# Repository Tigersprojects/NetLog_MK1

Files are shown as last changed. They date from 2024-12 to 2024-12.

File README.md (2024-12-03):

# NetLog MK1
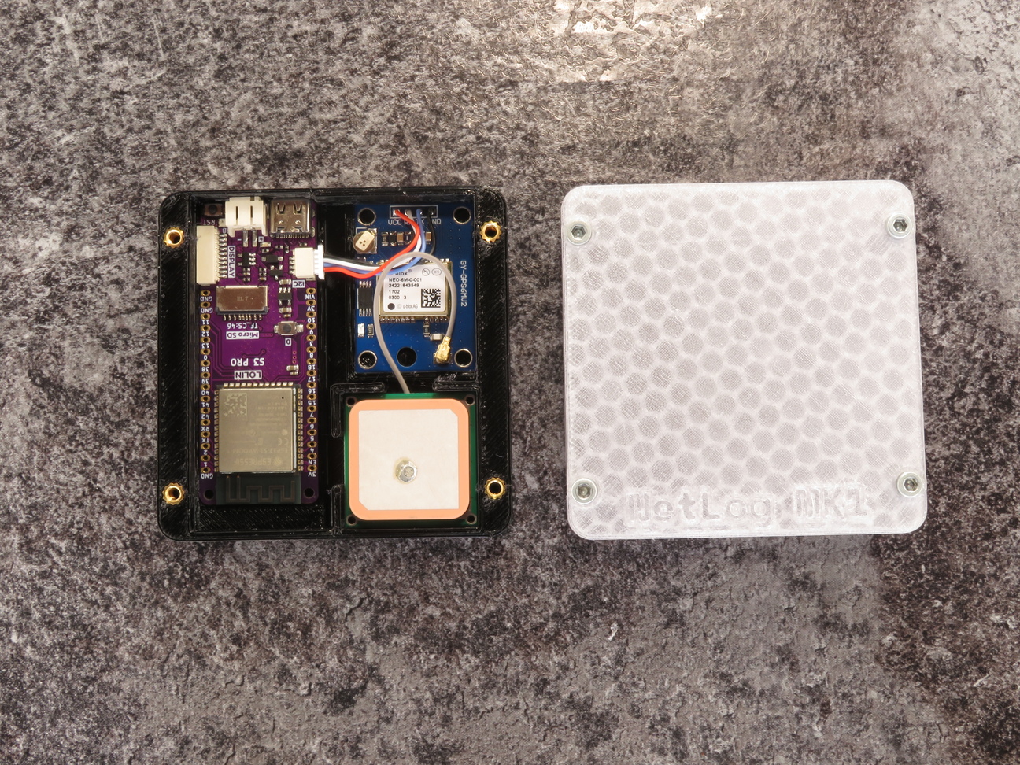
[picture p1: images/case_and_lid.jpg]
NetLog MK1 top view

The NetLog MK1 is a WiFi network scanning (wardriving) device based on
the ESP32-S3 and an inexpensive GPS module.

The NetLog MK1 is designed to be operated from a power bank or car USB charger.
The networks are stored in a CSV file on a FAT12 or FAT16 filesystem.

The NetLog MK1 will appear as a USB disk once connected to a computer.
From there, you can open the CSV file with any spreadsheet software (like LibreOffice, Google Docs, etc).

- [Build your own](docs/build_tutorial.md)
- [Flashing the firmware](docs/flashing_tutorial.md)

## RGB LED light codes
| Light code | Meaning |
|---|---|
| Static yellow  | Device starting |
| Static red | FS error. Format with FAT12 or FAT16  |
| Blinking green | Establishing GPS fix |
| Blinking red | Could not communicate with GPS module |
| White blink | Network found |

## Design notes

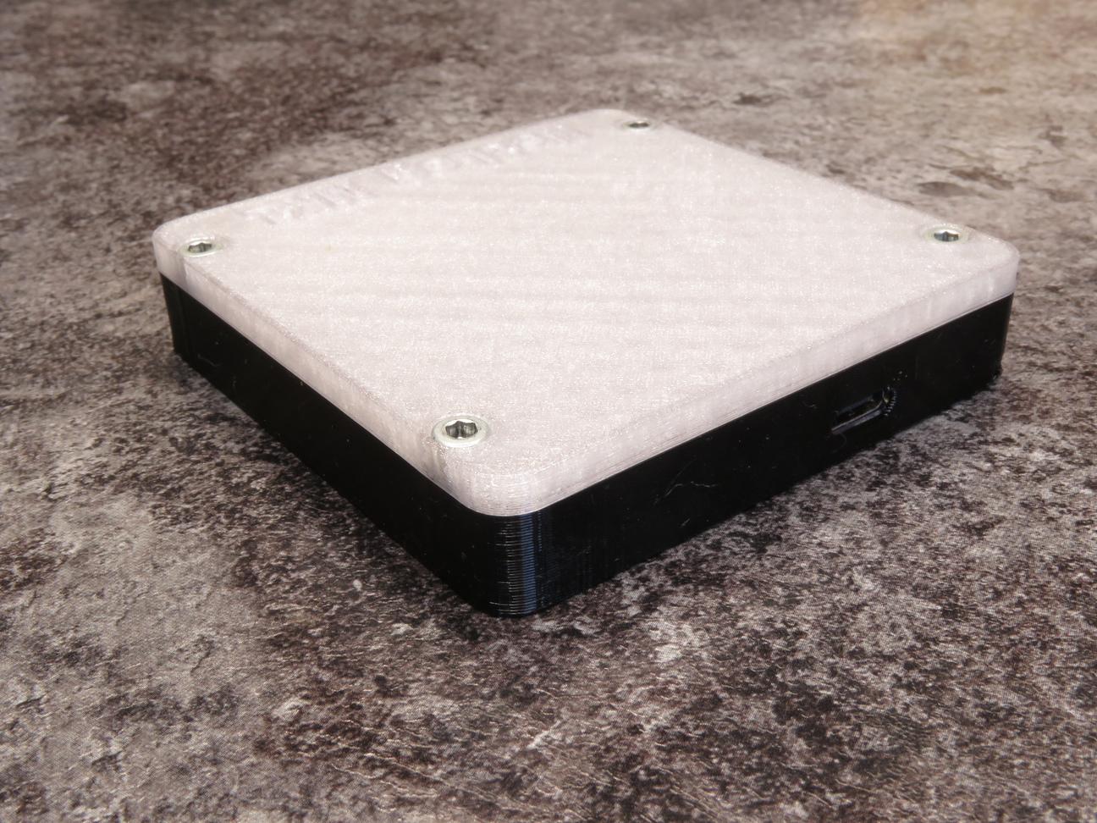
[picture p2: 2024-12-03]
images/side.jpg

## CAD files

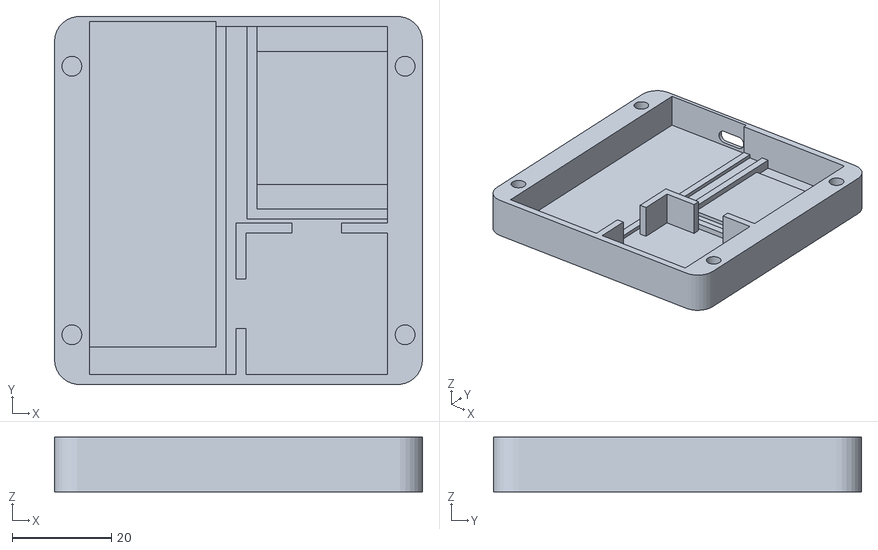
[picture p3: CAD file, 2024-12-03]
case.stl
74.0 x 74.0 x 11.0

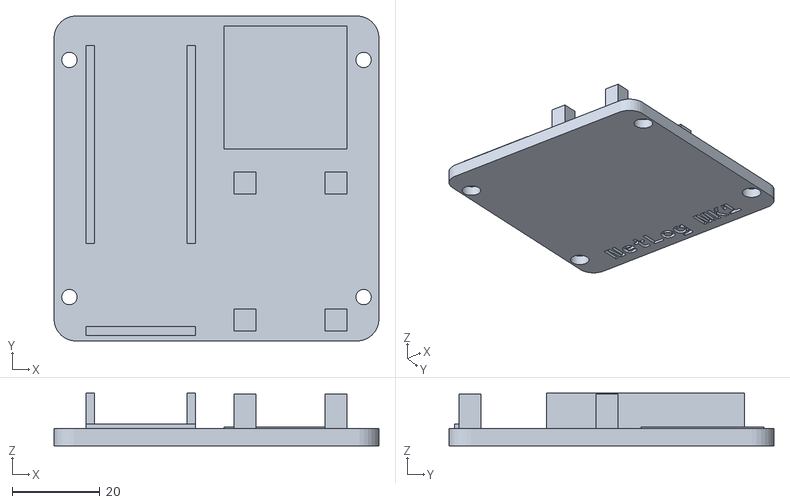
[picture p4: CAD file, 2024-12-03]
lid.stl
74.0 x 74.0 x 12.0

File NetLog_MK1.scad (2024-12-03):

/*
  Case for the NetLog MK1.

  Use with M3 threaded inserts
  and M3 hex socket cap screws.
  
  This file is a mess.
*/


$fn=30;

// Area for the components, e.g. GPS module, MCU, antenna //
case_x = 60;
case_y = 70;
case_z = 9;

// Mainboard size //
mainb_l = 65.5;
mainb_w = 25.5;
mainb_h = 1;

// GPS module size //
gps_l = 36.75;
gps_w = 26.25;
gps_h = 1.5;

// GPS antenna size //
gpsa_l = 28.5;
gpsa_w = 28.5;
gpsa_h = 9;

// Mainboard USB-C connector offsets //
mainb_usb_x = 16;
mainb_usb_z = 0.75;

// Tolerance offset //
tolerance_offset = 0.25;

// Other stuff //
wall_thickness = 2;

box = true;
lid = true;

lid_thickness = 4;

text_font = "Space Mono:style=Bold";


// A hole for a screw //
module screwHole() {
  translate([2.75, 2.875, 3]) cylinder(1, d=3.5);
  translate([2.75, 2.875]) cylinder(3, d=5.75);
}


// Box //
if (box) {

  // Rounded corners //
  for (i = [0 : 1 : 1]) {
    difference() {

      translate([
        5 + i * (case_x + wall_thickness * 2), 5
      ]) hull() {
        
        cylinder(case_z + wall_thickness, d=5 * 2);
        
        translate([0, case_y - 10 + wall_thickness * 2])
          cylinder(case_z + wall_thickness, d=5 * 2);
      }

      translate([
        5 + i * (case_x + wall_thickness * 2 - 5), 0
      ]) cube([
        5, case_y + wall_thickness * 2,
        case_z + wall_thickness
      ]);
      

      // Holes for screws //
      for (j = [0 : 1 : 1]) translate([
        i * (case_x + 5 + wall_thickness * 2 - 2) + 3.5,

        10 + j *
        (case_y - 20 + wall_thickness * 2),
        
        case_z + wall_thickness - 10.5
      ]) cylinder(10.5, d=4);
    }
  }

  translate([5, 0]) {

    // Box for the components //
    difference() {
      cube([
        case_x + wall_thickness * 2,
        case_y + wall_thickness * 2,
        case_z + wall_thickness
      ]);
      
      translate([wall_thickness, wall_thickness, wall_thickness]) cube([
        case_x,
        case_y,
        case_z
      ]);
      

      // Holes for screws //
      for (i = [0 : 1 : 1]) for (j = [0 : 1 : 1]) translate([
        i * (case_x + 5 + wall_thickness * 2 - 2) - 1.5,
        
        10 + j *
        (case_y - 20 + wall_thickness * 2),
        
        case_z + wall_thickness - 10.5
      ]) cylinder(10.5, d=4);


      // Small pits under GPS module //
      translate([
        case_x - gps_w + wall_thickness,
        case_y - gps_l + wall_thickness,
        wall_thickness / 2
      ]) cube([gps_w, 5, wall_thickness / 2]);

      translate([
        case_x - gps_w + wall_thickness,
        case_y - 5 + wall_thickness,
        wall_thickness / 2
      ]) cube([gps_w, 5, wall_thickness / 2]);


      // Hole for USB-C port //
      translate([
        wall_thickness + 1.875 + mainb_usb_x,
        wall_thickness * 2 + case_y,
        wall_thickness + 1.875 + mainb_usb_z
      ]) { 

        rotate([90, 90]) {
          hull() {
            cylinder(wall_thickness, d=3.5);
            translate([0, 5]) cylinder(wall_thickness, d=3.5);
          }
        }
      }

      // Make the wall thinner where the mainboard goes
      translate([wall_thickness, wall_thickness + case_y, wall_thickness])
        cube([mainb_w, wall_thickness / 2, case_z]);
    }

    // Holders for the mainboard //
    translate([wall_thickness + mainb_w, wall_thickness, wall_thickness])
      cube([wall_thickness, case_y, mainb_h]);
  
    translate([wall_thickness, wall_thickness, wall_thickness])
      cube([mainb_w, case_y - mainb_l + wall_thickness / 2, mainb_h]); 

    // Holders for the GPS module //
    translate([case_x - gps_w, case_y - gps_l, wall_thickness])
      cube([wall_thickness, gps_l + wall_thickness, gps_h]);
  
    translate([
      case_x - gps_w + wall_thickness,
      case_y - gps_l,
      wall_thickness
    ]) cube([gps_w, wall_thickness, gps_h]);
  

    // Holders for the GPS antenna //
    difference() {
      translate([case_x - gpsa_w, wall_thickness, wall_thickness])
        cube([gpsa_w + wall_thickness, gpsa_l + wall_thickness, gpsa_h]);

      translate([
        case_x - gpsa_w + wall_thickness,
        wall_thickness,
        wall_thickness
      ]) cube([gpsa_w, gpsa_l, gpsa_h]);

      translate([
        case_x - gpsa_w / 2 + wall_thickness - 5,
        gpsa_l + wall_thickness,
        wall_thickness
      ]) cube([10, wall_thickness, gpsa_h]);

      translate([
        case_x - gpsa_w,
        gpsa_l / 2 + wall_thickness - 5,
        wall_thickness
      ]) cube([wall_thickness, 10, gpsa_h]);
    }
  }
}


// Lid //
if (lid) {  
  translate([0, case_y + wall_thickness * 2 + 10]) {

    // Rounded corners //
    for (i = [0 : 1 : 1]) {
      difference() {

        translate([
          5 + i * (case_x + wall_thickness * 2), 5
        ]) hull() {
          
          cylinder(lid_thickness, d=5 * 2);
          
          translate([0, case_y - 10 + wall_thickness * 2])
            cylinder(lid_thickness, d=5 * 2);
        }

        translate([
          5 + i * (case_x + wall_thickness * 2 - 5), 0
        ]) cube([
          5, case_y + wall_thickness * 2,
          lid_thickness
        ]);
        

        // Screw holes //
        for (j = [0 : 1 : 1]) translate([
          i * (case_x + 5 + wall_thickness * 2 - 2) + 0.75,

          7.125 + j *
          (case_y - 20 + wall_thickness * 2), 0
        ]) screwHole();
      }
    }


    // Box for the lid //
    difference() {
      translate([5, 0]) cube([
        case_x + wall_thickness * 2,
        case_y + wall_thickness * 2,
        lid_thickness
      ]);


      // Text //
      translate([
        case_x / 2 + 5 + wall_thickness,
        case_y + wall_thickness * 2 - 2,
        wall_thickness / 2
      ]) rotate([180]) linear_extrude(wall_thickness / 2) 
        text(
          "NetLog MK1",
          6, font=text_font,
          halign="center",
          valign="bottom"
        );


      // More screw holes //
      for (i = [0 : 1 : 1]) for (j = [0 : 1 : 1]) translate([
        i * (case_x + 5 + wall_thickness * 2 - 2) + 0.75,

        7.125 + j *
        (case_y - 20 + wall_thickness * 2), 0
      ]) screwHole();
    }


    // Support for the thin mainboard wall //
    translate([5 + wall_thickness + tolerance_offset,
              tolerance_offset + wall_thickness / 2, lid_thickness])

              cube([mainb_w - tolerance_offset * 2, wall_thickness, 1]);


    translate([
      5 + wall_thickness,
      wall_thickness,
      lid_thickness
    ]) {
      
      // Holders for mainboard //
      for (i = [0 : 1 : 1]) translate([
        tolerance_offset + i * (mainb_w - wall_thickness - tolerance_offset * 2),
        case_y - 45 - tolerance_offset - (case_y - mainb_l)
      ]) cube([wall_thickness, 45, case_z - mainb_h]);


      // Holder for GPS antenna (+0.25mm height) //
      translate([
        case_x + tolerance_offset - gpsa_w,
        case_y + tolerance_offset - gpsa_l
      ]) cube([
        gpsa_w - tolerance_offset * 2,
        gpsa_l - tolerance_offset * 2,
        case_z - gpsa_h + 0.25
      ]);

      
      // Holders for GPS module (+0.25mm height) //
      for (i = [0 : 1 : 1]) for (j = [0 : 1 : 1]) translate([
        case_x - 5 - tolerance_offset - i * (gps_w - 5 - tolerance_offset * 2),
        tolerance_offset + j * (gps_l - 5 - tolerance_offset * 2),
      ]) cube([5, 5, case_z - gps_h + 0.25]);
    }
  }
}

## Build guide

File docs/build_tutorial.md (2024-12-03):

# Building a NetLog MK1
To build a NetLog MK1, you need the following tools and parts:

| Tools                 |
|-----------------------|
| Soldering iron        |
| Flushcutters          |
| 3D printer            |
| Wire strippers        |
| 2.5mm hex screwdriver |

| Parts                         |
|-------------------------------|
| LOLIN S3 Pro dev board        |
| 4x M3 threaded inserts        |
| 4x M3 hex socket cap screws   |
| GY-NEO6MV2 GPS module         |
| 28 x 28 x ~9mm uFL GPS antenna |
| JST SH 4-pin connector        |
| 4x JST SH cables              |

## Step 1: Building the case
Print `case.stl` with PLA or PET(G). Next, insert four M3 threaded inserts into the screw holes.
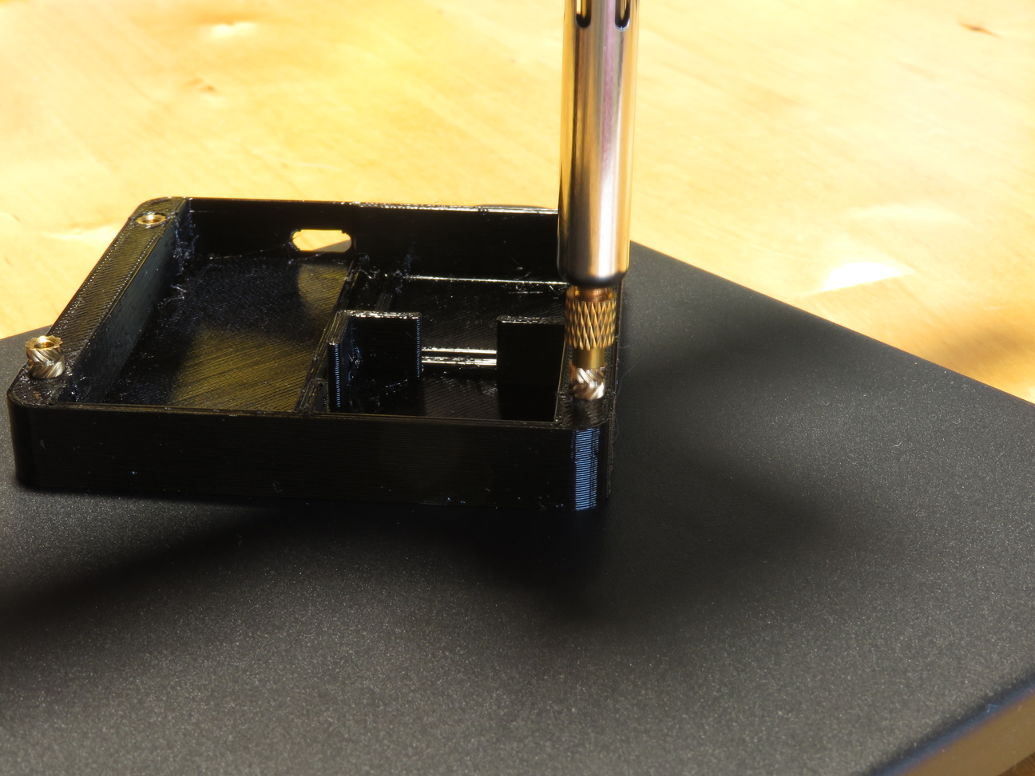
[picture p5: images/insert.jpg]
Inserting the inserts


When you're done, the case should look something like this:
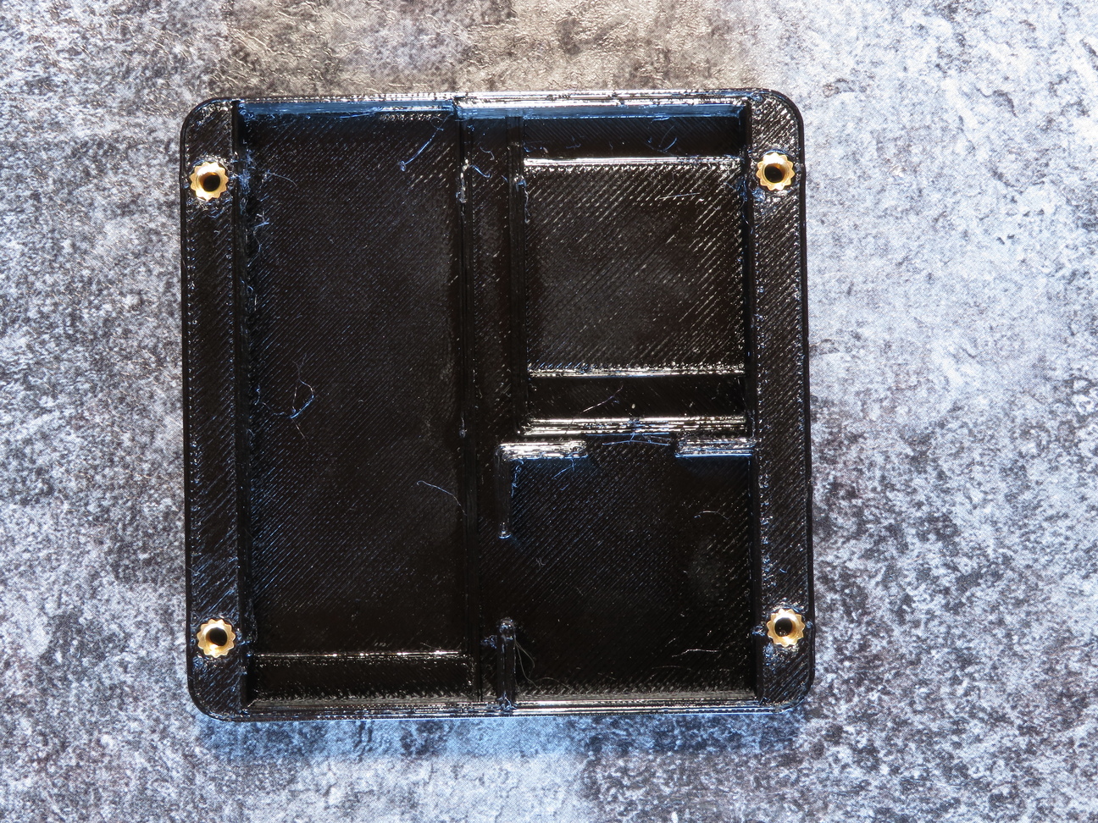
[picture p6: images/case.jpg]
Finished case


## Step 2: Preparing the GPS module
Next, we'll connect a JST SH (1.0mm) 4-pin cable to the GPS module.

I recommend getting a set that has pre-crimped cables, as manually crimping these connectors can be difficult.
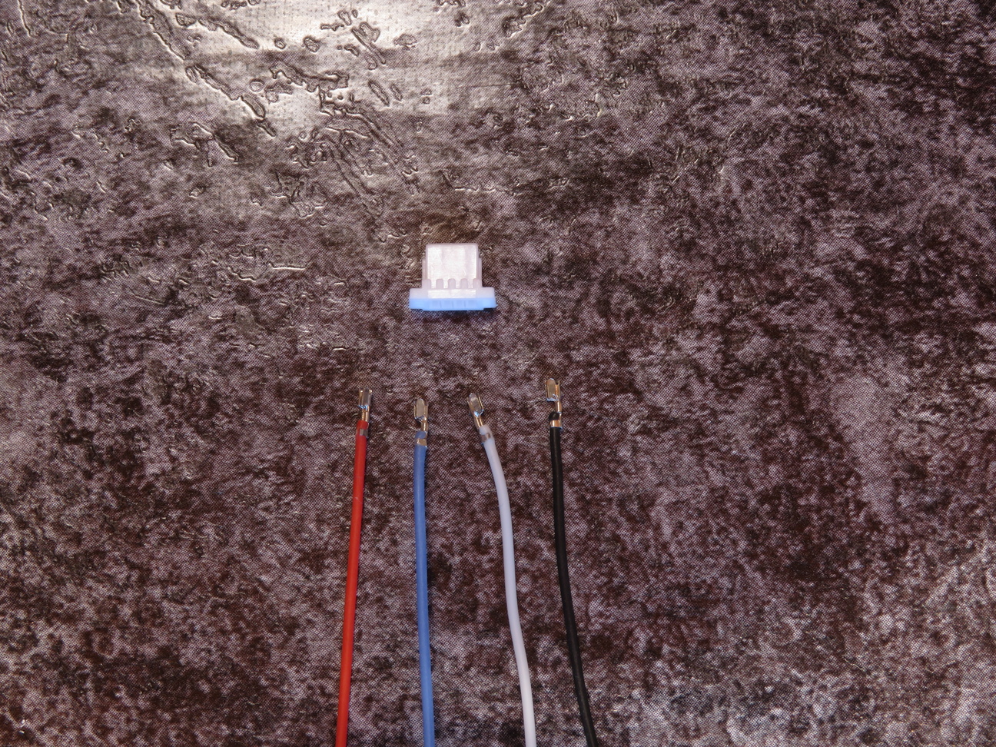
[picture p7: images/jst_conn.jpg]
JST connector with cables


Insert the cables into the connector, and cut the ends so they are about
5cm long, and strip the ends of the cables. Then, solder them to the GPS module with the pinout shown in the image below:
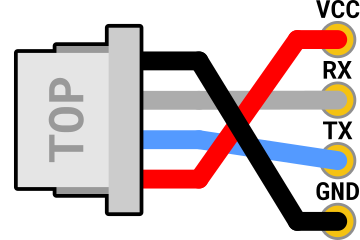
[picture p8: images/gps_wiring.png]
Connector pinout


This is what the result should look like:
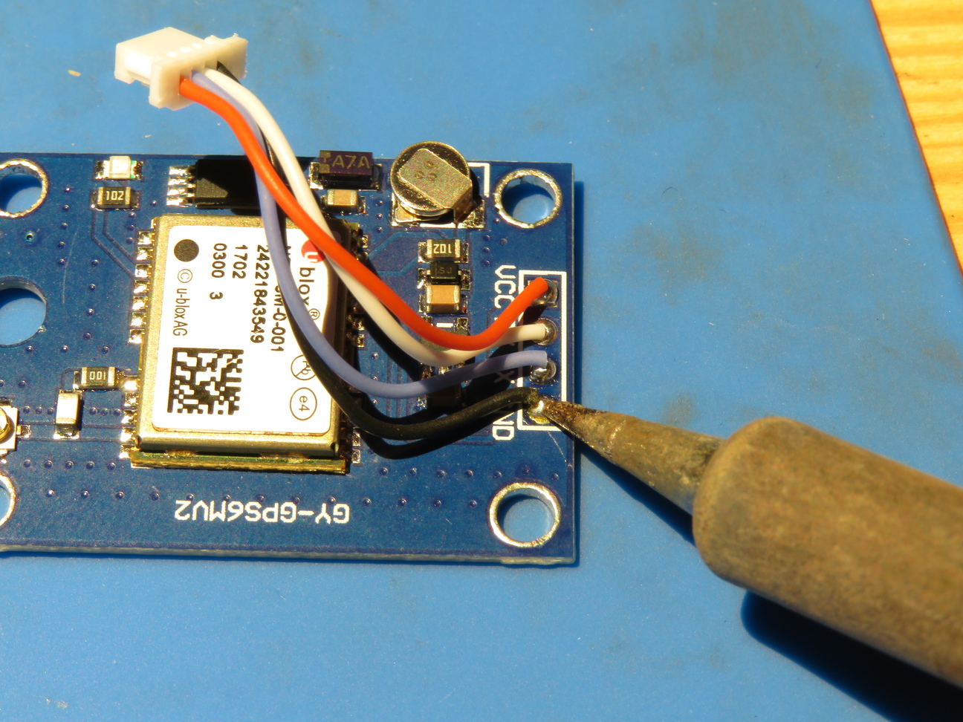
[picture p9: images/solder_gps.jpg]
Result


For the GPS module to fit in the case, you will need to cut the solder blobs on the bottom of the GPS module:
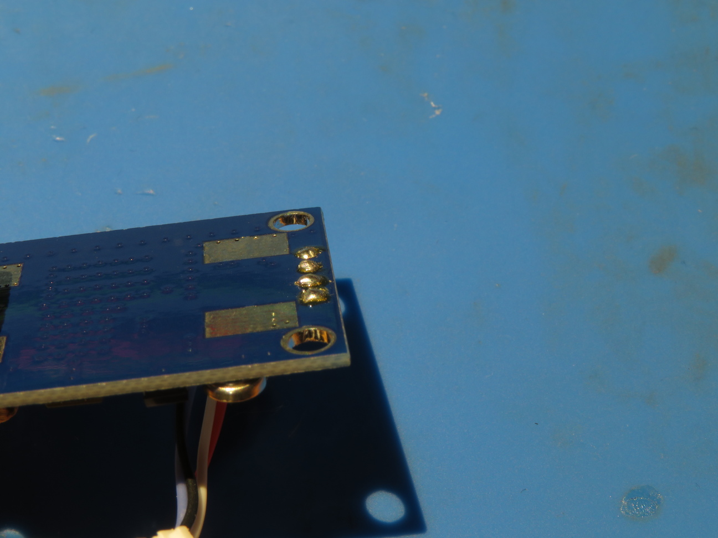
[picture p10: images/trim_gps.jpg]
Flush solder blobs


## Step 3: Printing the cover
Print `lid.stl` with **clear** PLA or PET(G). This is so that the LEDs can shine through the cover.
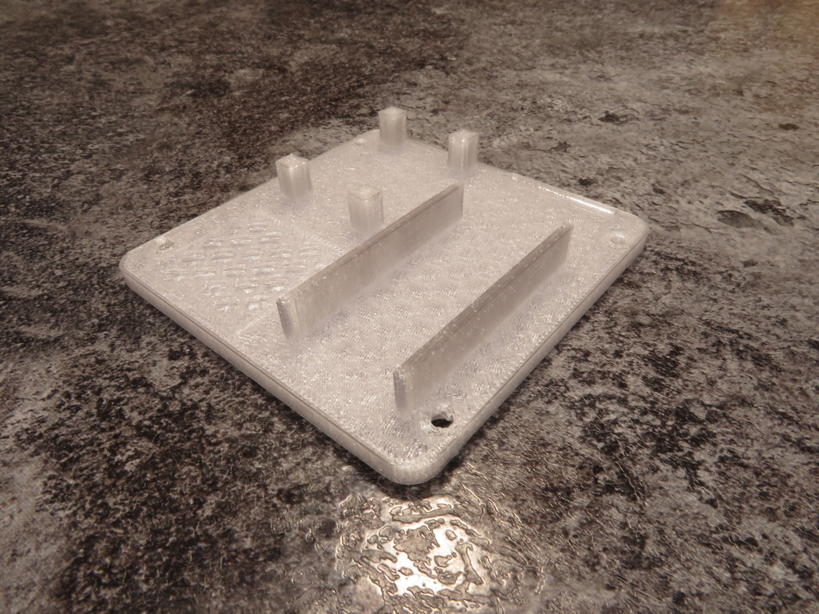
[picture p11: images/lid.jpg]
Cover

Those weird towers on the cover hold the components in place.

## Step 4: Assembling the device
Now we have the case, cover, and components ready for assembly.
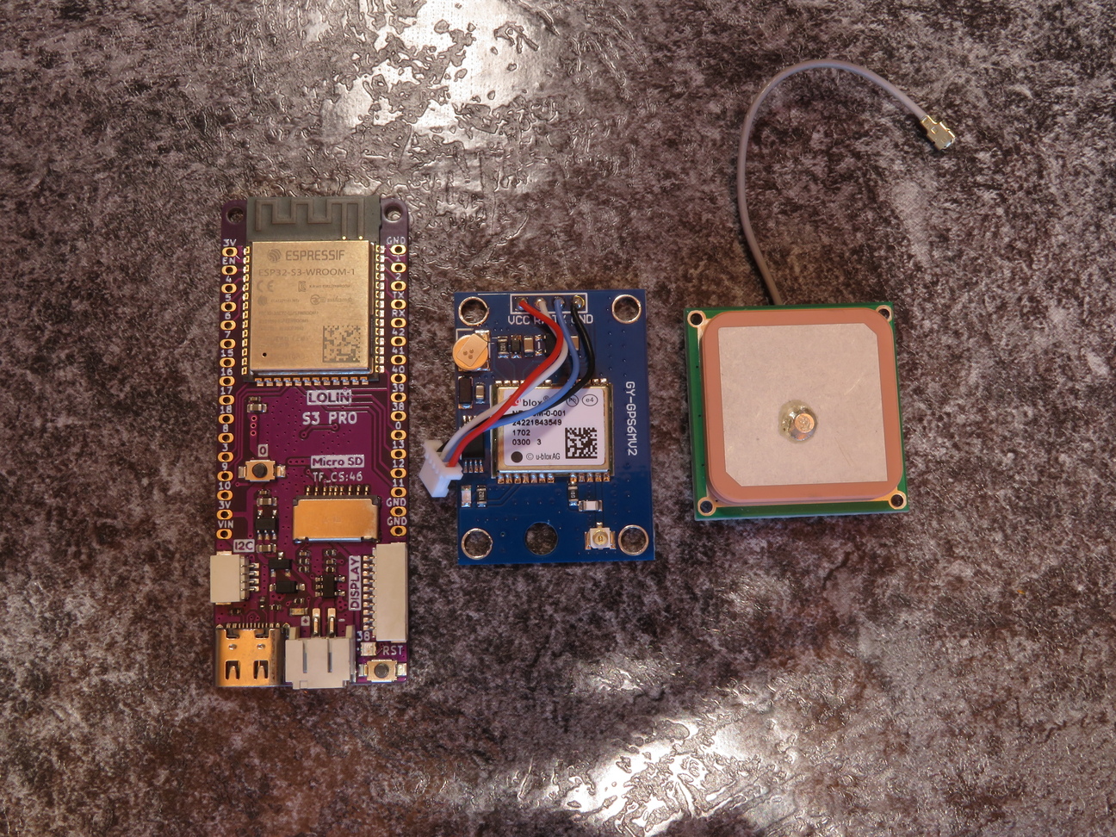
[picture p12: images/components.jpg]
Components


Put the components in the case like this:
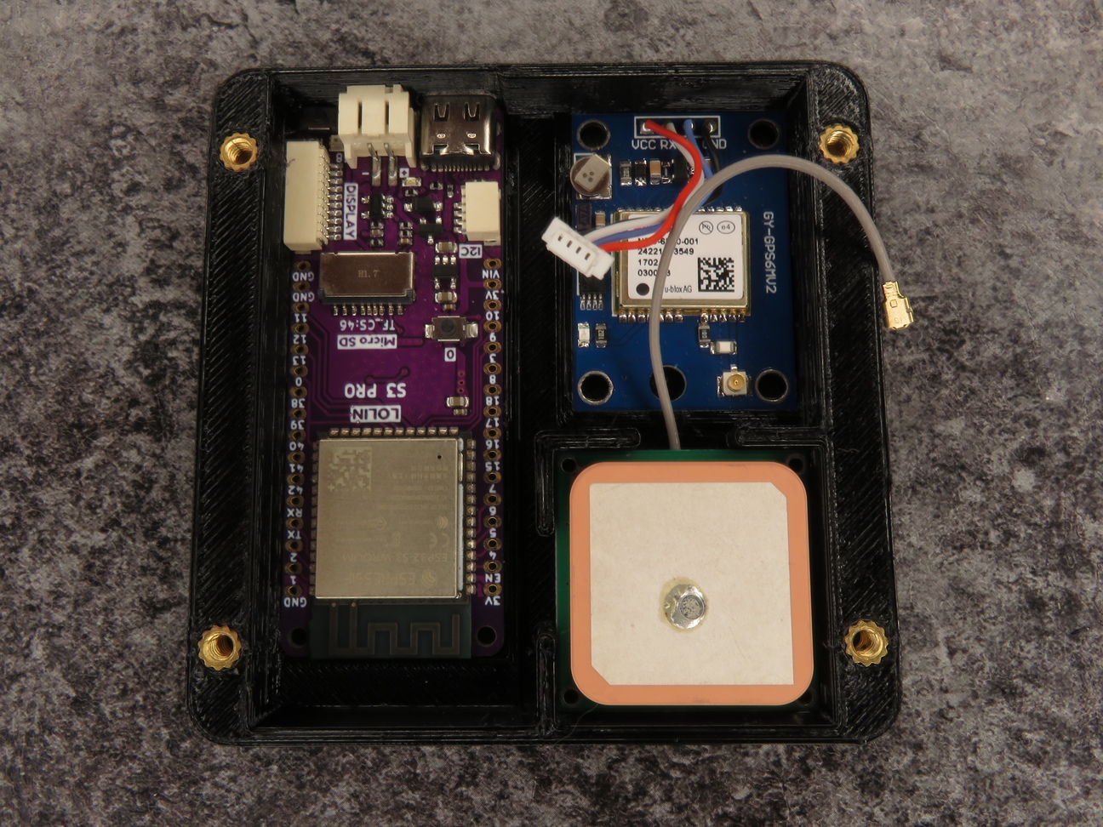
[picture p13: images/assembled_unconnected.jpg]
Components in case


> Note: Due to tight tolerances, getting the components in their slots may take some force.

Next, connect the JST cable of the GPS module into the S3 Pro's I2C port, and the GPS antenna's uFL connector to the GPS module.
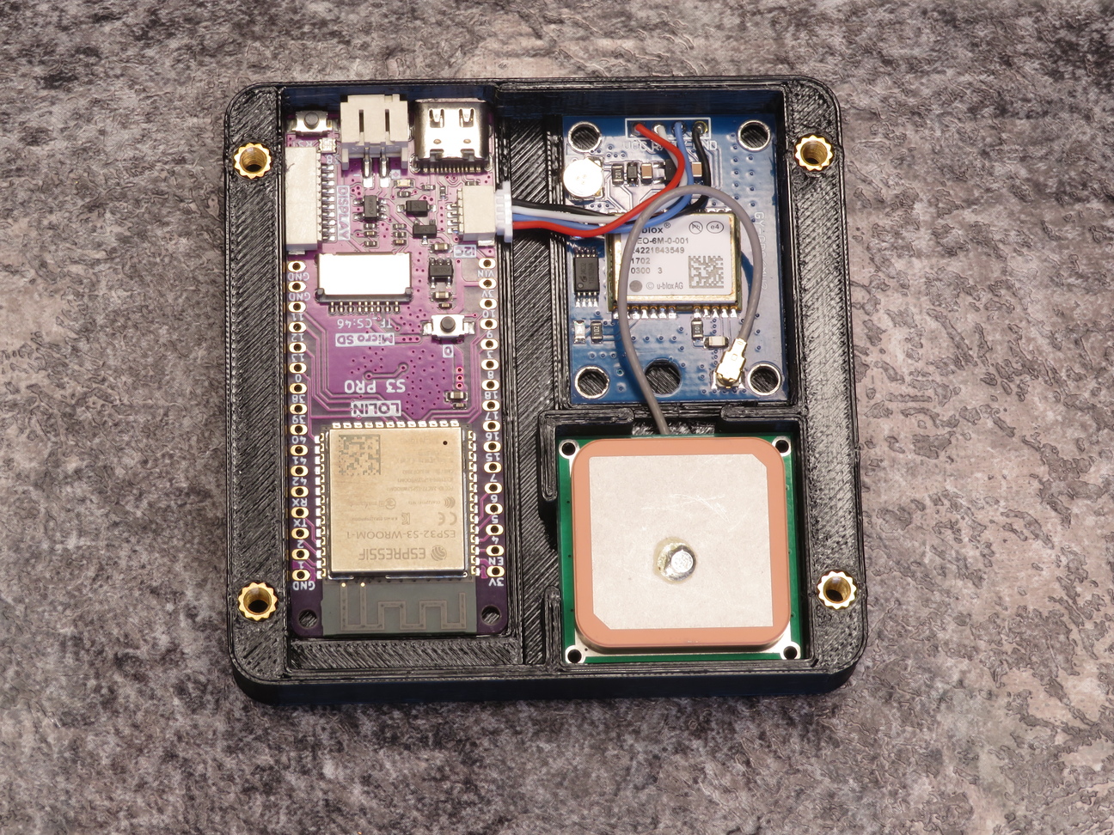
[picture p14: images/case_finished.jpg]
Case with cables connected


> While the 4-pin JST connector on the S3 Pro is intended for I2C,
    the versatility of the ESP32's GPIO pins allows us to use it for
    UART as well.

> Before attaching the cover, it may be a good idea to [flash the firmware.](flashing_tutorial.md)

Now, we can screw the cover on to the case:
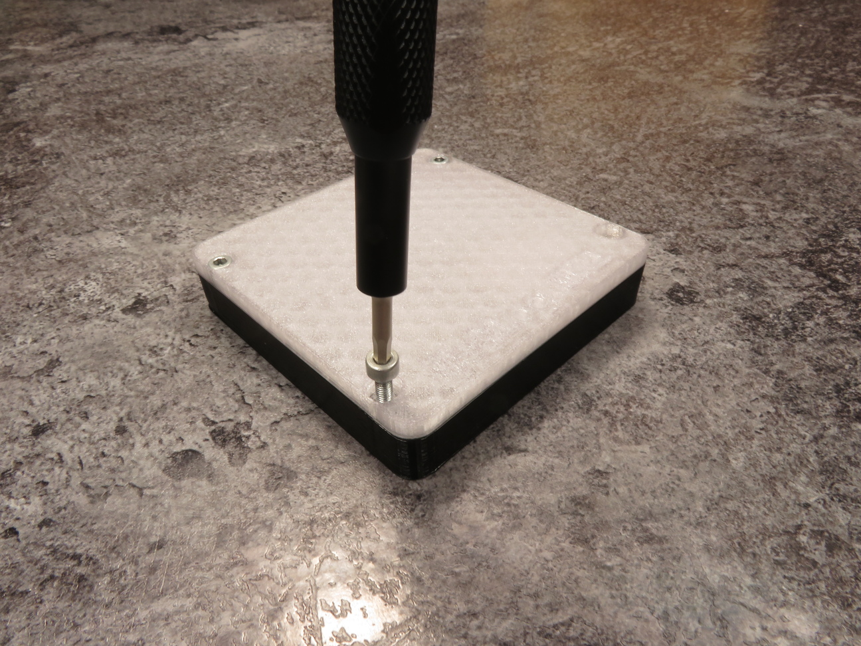
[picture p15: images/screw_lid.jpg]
Screwing cover on case


With this, your NetLog MK1 is finished!
In case you haven't already, you now just have to [flash the firmware.](flashing_tutorial.md)

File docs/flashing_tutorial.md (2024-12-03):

# Flashing the Firmware

Open `NetLog_MK1.ino` in Arduino IDE and install the following
boards and libraries:

1. [Install the ESP32 boards](https://docs.espressif.com/projects/arduino-esp32/en/latest/installing.html)

2. Install the following libraries:
    - TinyGPSplus
    - Adafruit NeoPixel
    - SdFat
    - Adafruit SPIFlash
    - Adafruit TinyUSB

If you want, you can configure some parameters in `config.h`. Next,
select `LOLIN S3 Pro` and the connected serial port in the board selector.

Then, under the _Tools_ menu:

- enable _USB CDC On Boot_
- set _USB Mode_ to _USB-OTG (TinyUSB)_
- set _Partition Scheme_ to _16M Flash (2MB APP/12.5MB FATFS)_

Once you've done that, upload the sketch by clicking on the upload button.
Selecting the board

> Flashing the firmware through hardware CDC is not possible
    once the device is mounted as a USB flash drive.
    Instead of booting into DFU mode, you can set _Upload Mode_ to
    _USB-OTG CDC (TinyUSB)_.

Once you've flashed the firmware and restarted the device, the LED will glow yellow and then turn solid red.
This indicates a filesystem error, as we first have to format the FATFS partition with FAT12 or FAT16.

On Linux you can format the device by running `sudo mkfs.vfat /dev/sdX`,
with `sdX` being the block device, which you can find by running `lsblk`.

Now the device should be ready for use.

> The BSSIDs text file the device creates contains the BSSID
    of every network it has already found (which networks it should ignore).

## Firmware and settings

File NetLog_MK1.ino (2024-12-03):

/*
  NetLog MK1 - The ESP32 WiFi logger
  by Tigersprojects

  Designed for an ESP32-S3 with a GPS module.

  Remember to set "USB CDC On Boot" to "Enabled"
  and "USB Mode" to "USB-OTG" under the Tools menu.

  You can usually set "Upload Mode" to
  "USB-OTG CDC (TinyUSB)" to avoid booting
  the device into DFU mode.

  Format the flash with FAT12 or FAT16
  for NetLog to work properly.
*/

#include <WiFi.h>

#include <Wire.h>
#include <TinyGPS++.h>
#include <Adafruit_NeoPixel.h>

#include "SPI.h"
#include "SdFat.h"
#include "Adafruit_SPIFlash.h"
#include "Adafruit_TinyUSB.h"

// For flashTransport definition
#include "flash_config.h"

#include "config.h"

// Define stuff //
String cur_ssid, csv_str;

char cur_bssid[18],
     temp_bssid[18],
     newline_bssid[19],
     temp_char;

bool exists = false,
     gps_new_data = false,
     flash_busy = false;

HardwareSerial neogps(1);
Adafruit_SPIFlash flash(&flashTransport);

FatVolume fatfs;
FatFile bssid_file;

TinyGPSPlus gps;
Adafruit_USBD_MSC usb_msc;


// Checks if a file exists
bool fileExists(const char *path) {
  FatFile file = fatfs.open(path);

  bool exists = file;
  if (exists) file.close();

  return exists;
}


// Writes to a file
void fileAppend(const char *path, const char *message) {
  File file = fatfs.open(path, FILE_WRITE);

  if (!file) return;

  file.print(message);
  file.close();
}


// Makes a string CSV-safe
String CSVSafeString(String input) {
  String output = "";

  // Double all quotes
  for (int c = 0; c < input.length(); c++) {
    output += ((input.charAt(c) == '"') ? "\"\"" : String(input.charAt(c)));
  }

  // Append and prepend quotes to the output
  output = "\"" + output + "\"";
  return output;
}


// Setup
void setup() {

  // Initialize NeoPixel
  rgb.begin();

  rgb.setPixelColor(0, rgb.Color(255, 255, 0));
  rgb.setBrightness(neopixel_brightness);

  rgb.show();

  // Init WiFi
  WiFi.mode(WIFI_STA);
  WiFi.disconnect();

  delay(1000);

  // Initialize storage
  flash.begin();

  // Configure usb_msc
  usb_msc.setID(netlog_vid, netlog_name, netlog_ver);
  usb_msc.setReadWriteCallback(msc_read_cb, msc_write_cb, msc_flush_cb);
  usb_msc.setCapacity(flash.size() / 512, 512);

  usb_msc.setUnitReady(true);
  usb_msc.begin();

  // Reattach if already mounted
  if (TinyUSBDevice.mounted()) {
    TinyUSBDevice.detach();
    delay(10);
    TinyUSBDevice.attach();
  }

  // Init fs on flash
  while (!fatfs.begin(&flash)) {
    rgb.setPixelColor(0, rgb.Color(255, 0, 0));
    rgb.show();

    delay(1000);
  }

  // Create necessary files if they don't exist
  if (!fileExists(data_filename)) {
    flash_busy = true;
    fileAppend(data_filename, "ssid,bssid,rssi,auth,coord,speed\n");
    flash_busy = false;
  }

  if (!fileExists(bssid_filename)) {
    flash_busy = true;
    fileAppend(bssid_filename, "");
    flash_busy = false;
  }

  // Connect to GPS
  neogps.begin(9600, SERIAL_8N1, GPS_RXD2, GPS_TXD2);
  delay(2000);

  // Startup successful (with cool fade effect)
  for (int b = 0; b < neopixel_brightness; b++) {
    rgb.setBrightness(neopixel_brightness - b);
    rgb.show();

    delay(5);
  }

  rgb.setPixelColor(0, rgb.Color(0, 0, 0));
  rgb.setBrightness(neopixel_brightness);
  rgb.show();

  delay(500);
}


// Loop
void loop() {

  // See if there is available data from the GPS module
  for (unsigned long start = millis(); millis() - start < 1000;) {
    while (neogps.available()) {
      if (gps.encode(neogps.read())) {
        gps_new_data = true;
      }
    }
  }

  // Start scanning networks if the GPS module has a connection
  if (gps.location.isValid() && gps.satellites.value() != 0) {

    // Make sure NeoPixel is off
    rgb.setPixelColor(0, rgb.Color(0, 0, 0));
    rgb.show();

    // Scan networks
    unsigned long networks_found = WiFi.scanNetworks();

    // Search for new networks
    for (int i = 0; i < networks_found; i++) {

      // Get SSID and stop at newline char ('\n')
      // (Yes, you can put newlines in SSIDs)    
      cur_ssid = WiFi.SSID(i).substring(0, WiFi.SSID(i).indexOf('\n'));

      // Get BSSID
      memset(cur_bssid, '\0', 18);
      WiFi.BSSIDstr(i).toCharArray(cur_bssid, 18);

      // Open BSSID file and make sure the BSSID doesn't already exist
      bssid_file = fatfs.open(bssid_filename);
      exists = false;

      while (bssid_file.available()) {

        // Check first character for maximum speed
        temp_char = bssid_file.read();

        if (temp_char == cur_bssid[0]) {

          // Read entire string if the characters match
          memset(temp_bssid, '\0', 18);

          while (temp_char != '\n') {
            strncat(temp_bssid, &temp_char, 1);
            temp_char = bssid_file.read();
          }

          if (strcmp(temp_bssid, cur_bssid) == 0) {
            exists = true;
            break;
          }

        } else {

          // Go to next newline if the characters don't match
          while (bssid_file.read() != '\n');
        }
      }

      bssid_file.close();


      // Save network info
      if (!exists) {

        // Flash NeoPixel to signal network
        rgb.setPixelColor(0, rgb.Color(255, 255, 255));
        rgb.show();

        delay(100);

        rgb.setPixelColor(0, rgb.Color(0, 0, 0));
        rgb.show();

        delay(100);

        // Add SSID, BSSID, and RSSI to CSV
        csv_str = CSVSafeString(cur_ssid) + "," +
                  CSVSafeString(cur_bssid) + "," +
                  CSVSafeString(String(WiFi.RSSI(i)) + " dBm") + ",";

        // Append auth to CSV
        switch (WiFi.encryptionType(i)) {
          case WIFI_AUTH_OPEN:
            csv_str += CSVSafeString("Open"); break;

          case WIFI_AUTH_WEP:
            csv_str += CSVSafeString("WEP"); break;

          case WIFI_AUTH_WPA_PSK:
            csv_str += CSVSafeString("WPA PSK"); break;

          case WIFI_AUTH_WPA2_PSK:
            csv_str += CSVSafeString("WPA2 PSK"); break;

          case WIFI_AUTH_WPA_WPA2_PSK:
            csv_str += CSVSafeString("WPA WPA2 PSK"); break;

          case WIFI_AUTH_WPA2_ENTERPRISE:
            csv_str += CSVSafeString("WPA2 Enterprise"); break;
          
          case WIFI_AUTH_WPA3_PSK:
            csv_str += CSVSafeString("WPA3 PSK"); break;

          case WIFI_AUTH_WPA2_WPA3_PSK:
            csv_str += CSVSafeString("WPA2 WPA3 PSK"); break;

          case WIFI_AUTH_WAPI_PSK:
            csv_str += CSVSafeString("WAPI PSK"); break;

          default:
            csv_str += CSVSafeString(String("Unknown Auth (" +
                      String(WiFi.encryptionType(i)) + ")"));
            break;
        
        } csv_str += ",";

        // Save NetLog position and speed (skipping latitude)
        csv_str += CSVSafeString(String(
          ((gps.location.lat() >= 0) ? "+" : "") + String(gps.location.lat(), 6) + " " +
          ((gps.location.lng() >= 0) ? "+" : "") + String(gps.location.lng(), 6)
        )) + ",";

        csv_str += CSVSafeString(String(gps.speed.kmph(), 1) + " km/h") + "\n";

        // Create BSSID with a newline
        memset(newline_bssid, '\0', 19);
        strncpy(newline_bssid, cur_bssid, 18);
        strncat(newline_bssid, "\n", 1);

        // Append data to files
        flash_busy = true;

        if (!fileExists(data_filename))
          fileAppend(data_filename, "ssid,bssid,rssi,auth,coord,speed\n");

        fileAppend(data_filename, csv_str.c_str());
        fileAppend(bssid_filename, newline_bssid);

        flash_busy = false;
      }
    }

  } else {
    if (!gps_new_data) {

      // No connection to GPS module
      rgb.setPixelColor(0, rgb.Color(255, 0, 0));
      rgb.show();

      delay(500);

      rgb.setPixelColor(0, rgb.Color(0, 0, 0));
      rgb.show();

    } else {

      // Searching for satellites
      rgb.setPixelColor(0, rgb.Color(0, 255, 0));
      rgb.show();

      delay(500);

      rgb.setPixelColor(0, rgb.Color(0, 0, 0));
      rgb.show();
    }

    delay(500);
  }
}


// Callback for read command
int32_t msc_read_cb(uint32_t lba, void *buffer, uint32_t bufsize) {
  while (flash_busy);

  int32_t block = flash.readBlocks(lba, (uint8_t*)buffer, bufsize / 512) ? bufsize : -1;

  return block;
}


// Callback for write command
int32_t msc_write_cb(uint32_t lba, uint8_t *buffer, uint32_t bufsize) {
  while (flash_busy);

  int32_t block = flash.writeBlocks(lba, buffer, bufsize / 512) ? bufsize : -1;

  return block;
}


// Callback for flush command
void msc_flush_cb(void) {
  while (flash_busy);

  flash.syncBlocks();
  fatfs.cacheClear();
}
